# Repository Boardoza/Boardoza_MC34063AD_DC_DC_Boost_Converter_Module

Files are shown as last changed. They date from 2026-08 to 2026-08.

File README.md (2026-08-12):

# Boardoza MC34063A DC-DC Boost Converter Module

The **Boardoza MC34063A DC-DC Boost Converter Module** is a compact and efficient voltage step-up solution built around the reliable **MC34063A switching regulator IC**. This module is designed to convert a low DC input voltage into a higher regulated DC output voltage using a boost converter topology. With integrated current limiting and feedback regulation, the board provides stable and dependable power conversion for a wide variety of embedded and electronic applications.

Thanks to its compact PCB design and minimal external component requirement, this module is ideal for powering sensors, portable electronics, battery-operated systems, DIY electronics projects, and industrial control systems. The onboard status LED provides quick visual feedback for output operation, while the regulated switching architecture ensures efficient energy transfer and reduced power loss compared to linear regulator solutions.

## [Click here to purchase!](https://www.ozdisan.com/p/moduller-870/boardoza-mc34063ad-module-1591108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)

|Front Side|Back Side|
|:---:|:---:|
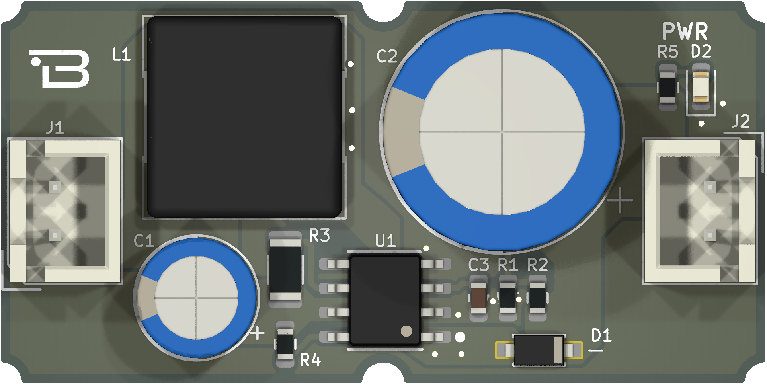
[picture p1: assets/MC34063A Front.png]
MC34063AD Front
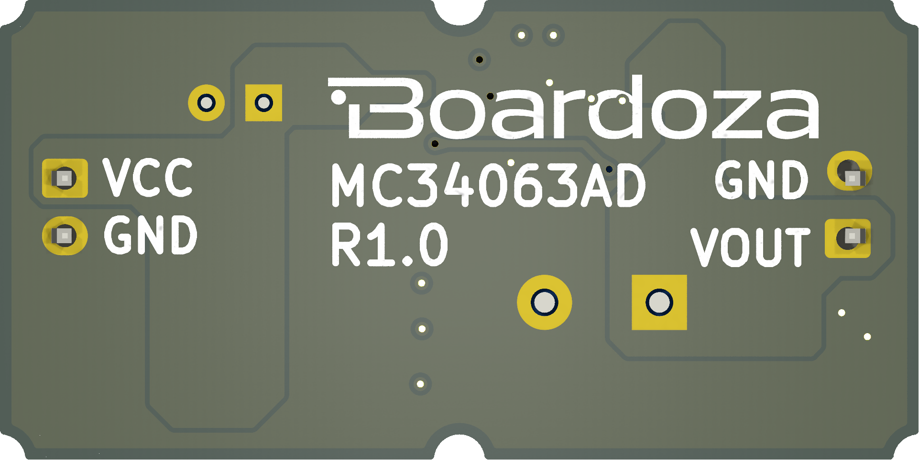
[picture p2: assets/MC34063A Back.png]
MC34063AD Back
| | |

---

## Key Features

- **Efficient DC-DC Boost Conversion:** Converts low DC input voltages into a stable higher output voltage.
- **Regulated Output Control:** Maintains consistent output voltage using an internal feedback regulation system.
- **Integrated Current Protection:** Includes short-circuit current limiting for improved reliability and safer operation.
- **Low Component Count:** Simplified external circuitry reduces design complexity and improves usability.
- **Status LED Indicator:** Onboard LED provides quick visual confirmation of output operation.
- **Suitable for Multiple Applications:** Ideal for embedded systems, DIY electronics, battery-powered devices, and power management projects.

---

## Technical Specifications

**Model:** MC34063AD   
**Manufacturer:** Boardoza  
**Manufacturer IC:** Texas Instruments      
**Functions:** DC-DC Boost Converter     
**Converter Topology:** Step-Up (Boost) Switching Regulator  
**Input Voltage:** 3 VDC to 12 VDC  
**Output Voltage:** 12 VDC Regulated  
**Output Current:** Up to 800mA  
**Switching Frequency:** Up to 100kHz  
**Reference Voltage Accuracy:** ±2%  
**Current Limiting:** Internal Short-Circuit Current Limiting  
**Operating Temperature:** 0°C to +75°C  
**Board Dimensions:** 40mm x 20mm  

---

## Board Pinout

### ( J1 ) Power Input Connector

| Pin Number | Pin Name | Description |
| :---: | :---: | --- |
| 1 | VIN | DC Input Voltage (3 VDC to 12 VDC) |
| 2 | GND | Ground |

### ( J2 ) Power Output Connector

| Pin Number | Pin Name | Description |
| :---: | :---: | --- |
| 1 | VOUT | Regulated 12 VDC Output |
| 2 | GND | Ground |

---

## Board Dimensions

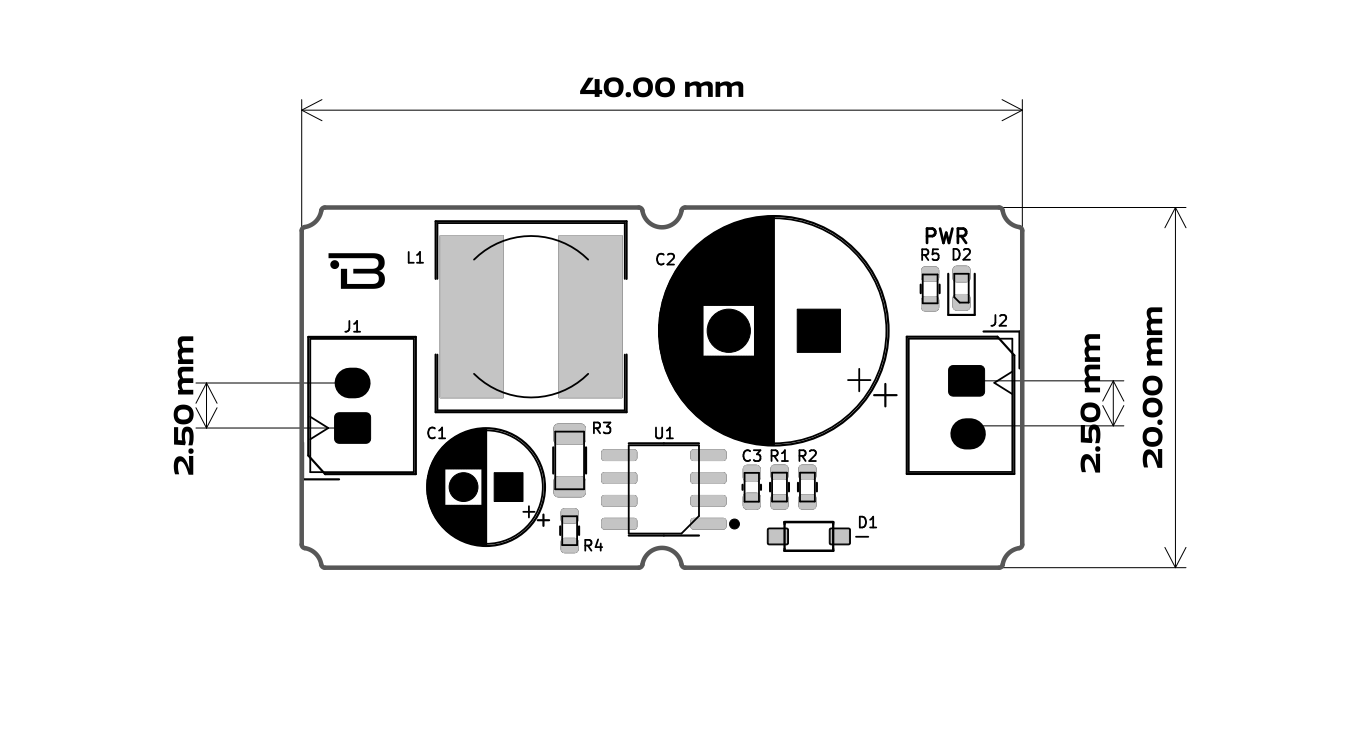
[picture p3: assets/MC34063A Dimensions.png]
MC34063AD Dimension


---

## Step Files

[Boardoza MC34063AD.step](./assets/MC34063A%20Step.step)

---

## Datasheet

[MC34063A Datasheet.pdf](./assets/MC34063A%20Datasheet.pdf)

---

## Version History

- V1.0.0 - Initial Release

---

## Support

- If you have any questions or need support, please contact support@boardoza.com

---

## **License**
### **Hardware Design**

[][cc-by-sa]

All hardware design files are licensed under [Creative Commons Attribution-ShareAlike 4.0 International License][cc-by-sa].

[cc-by-sa]: http://creativecommons.org/licenses/by-sa/4.0/
[cc-by-sa-shield]: https://img.shields.io/badge/License-CC%20BY--SA%204.0-lightgrey.svg

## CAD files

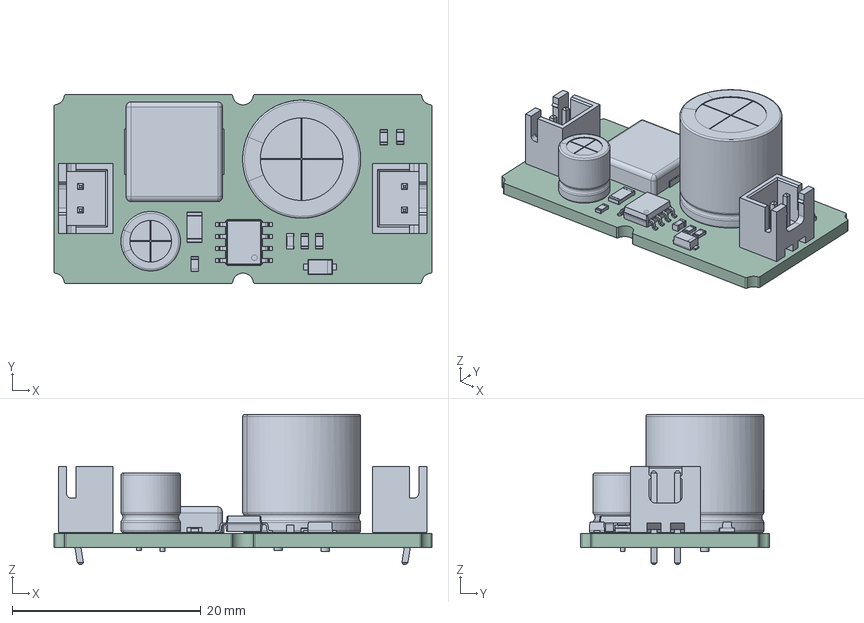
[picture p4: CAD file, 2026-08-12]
assets/MC34063A Step.step
40.0 x 20.0 x 15.9 mm
SOIC-8_3.9x4.9mm_P1.27mm
LED_0603_1608Metric
JST_XH_B2B-XH-A_1x02_P2.50mm_Vertical x 2
R_0603_1608Metric x 4
R_1206_3216Metric
D_SOD-123F
CP_Radial_D6.3mm_P2.50mm
L_APV_APH0615
C_0603_1608Metric
CP_Radial_D12.5mm_P5.00mm
kibot_gqcuvujy_PCB

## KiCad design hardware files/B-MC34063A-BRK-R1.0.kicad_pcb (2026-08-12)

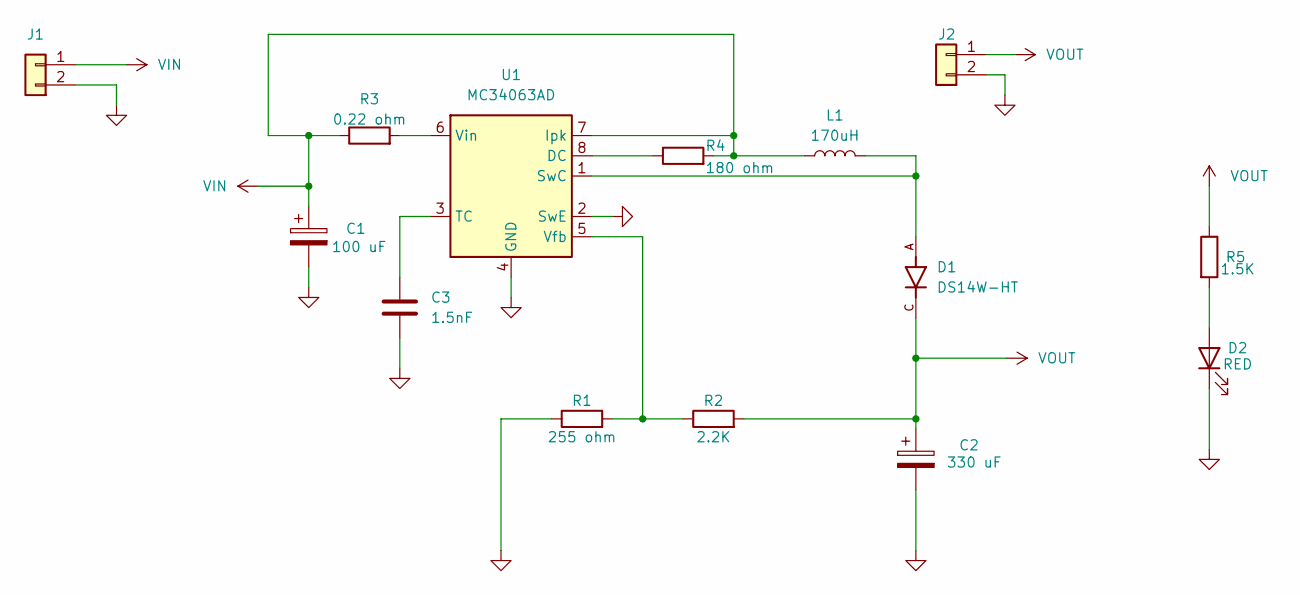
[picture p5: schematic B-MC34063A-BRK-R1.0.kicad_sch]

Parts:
C1: 100 uF; CP_Radial_D6.3mm_P2.50mm; MPN PF1V101MP26311UB7
C2: 330 uF; CP_Radial_D12.5mm_P5.00mm; MPN PKLH-063V331MH200
C3: 1.5nF; C_0603_1608Metric; MPN CL10B152JB8NNNC
D1: DS14W-HT; SODFL3816X120N; PARTREV 2021-07-12
D2: RED; LED_0603_1608Metric; MPN LTST-C190KRKT
J1, J2: Conn_01x02; 2317-02S_1x02_P2.50mm_Vertical; MPN 2317-02S
L1: 170uH; L_10.4x10.4_H4.8; MPN FPI1005-181M
R1: 255 ohm; R_0603_1608Metric; MPN 0603SAF2550T5E
R2: 2.2K; R_0603_1608Metric; MPN HP03W5F2201T5E
R3: 0.22 ohm; R_1206_3216Metric; MPN 1206S4F220LT5E
R4: 180 ohm; R_0603_1608Metric; MPN 0603SAJ0181T5E
R5: 1.5K; R_0603_1608Metric; MPN PS03W4F1501T5E
U1: MC34063AD; SOIC-8_3.9x4.9mm_P1.27mm; MPN MC34063AD-HTC

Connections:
GND: C1.2, C2.2, C3.2, D2.1 (K), J1.2, J2.2, R1.1, U1.2 (SwE), U1.4 (GND)
unnamed: D2.2 (A), R5.2
unnamed: R4.1, U1.8 (DC)
unnamed: D1.A, L1.2, U1.1 (SwC)
unnamed: C3.1, U1.3 (TC)
unnamed: R1.2, R2.1, U1.5 (Vfb)
unnamed: R3.2, U1.6 (Vin)
VIN: C1.1, J1.1, L1.1, R3.1, R4.2, U1.7 (Ipk)
VOUT: C2.1, D1.C, J2.1, R2.2, R5.1

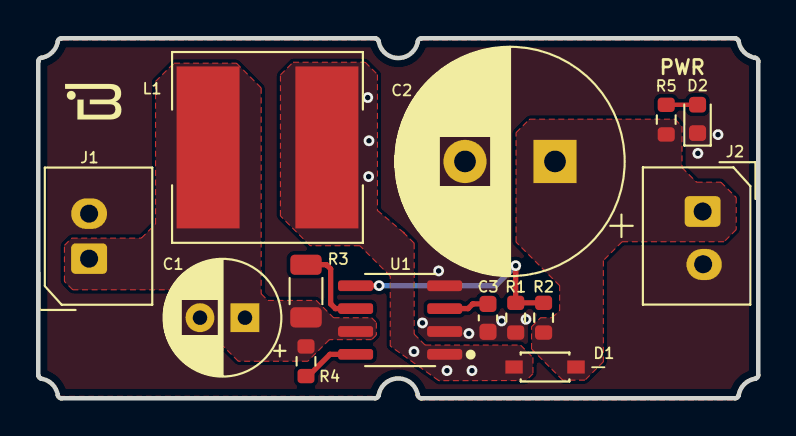
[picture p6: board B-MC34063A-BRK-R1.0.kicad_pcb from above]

Board: 2 copper layers, 40.0 x 20.0 mm, 14 parts (0 on the bottom side), 9 nets.

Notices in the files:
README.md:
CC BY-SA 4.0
